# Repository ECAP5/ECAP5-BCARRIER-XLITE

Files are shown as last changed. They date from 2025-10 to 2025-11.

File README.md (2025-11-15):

<br />
<div align="center">
    

  <h3 align="center">ECAP5-BCARRIER-XLITE</h3>

  <p align="center">
    Extra-light carrier board for the ECAP5-BSOM bringup
    <br />
    <a href="https://ecap5.github.io/ECAP5-BCARRIER-XLITE/"><strong>Explore the docs »</strong></a>
    <br />
  </p>
</div>

## Feature status

Status of the board feature's bringup :

<table>
  <thead>
    <tr>
      <th>Feature</th>
      <th>rev-1.0</th>
    </tr>
  </thead>
  <tbody>
    <tr>
      <td>Power input protections</td>
      <td>⏲️</td>
    </tr>
    <tr>
      <td>SOM power</td>
      <td>✅</td>
    </tr>
    <tr>
      <td>SOM JTAG</td>
      <td>⚠️</td>
    </tr>
    <tr>
      <td>SOM reset</td>
      <td>✅</td>
    </tr>
    <tr>
      <td>UART-to-USB</td>
      <td>⛔ (✅ with errata)</td>
    </tr>
    <tr>
      <td>SOM-to-SOM 8x differential-pairs bus</td>
      <td>⏲️</td>
    </tr>
    <tr>
      <td>SOM-to-SOM 16x single-ended bus</td>
      <td>⏲️</td>
    </tr>
    <tr>
      <td>SOM single-ended testpoint</td>
      <td>⏲️</td>
    </tr>
    <tr>
      <td>SOM differential-pair testpoint</td>
      <td>⏲️</td>
    </tr>
    <tr>
      <td>User LEDs</td>
      <td>⚠️</td>
    </tr>
    <tr>
      <td>User Buttons</td>
      <td>⏲️</td>
    </tr>
  </tbody>
</table>

See the [errata](https://ecap5.github.io/ECAP5-BCARRIER-XLITE/errata/1.0.html) for a full description of known issues.

## Licenses

- Software and configuration files are distributed under the GPL-3.0 license.
- Hardware is distributed under the CERN-OHL-S license.

See licence files for more information.

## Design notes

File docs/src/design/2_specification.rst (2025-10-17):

Specification
=============

.. requirement:: U_POWER_01
   :rationale: The board will be powered by a lab bench power supply.

   The board shall include a 2x1 terminal block connector for power input with a voltage range of 9V to 15V.

.. requirement:: U_POWER_02

   The board shall include reverse polarity and ESD protection after the power input connector.

.. requirement:: U_POWER_03

   The board shall include a 9-15V to 3.3V voltage regulator.

.. requirement:: U_POWER_04

   An LED shall be connected to the 3.3V regulator output.

.. requirement:: U_SOM_01

   The board shall include two DDR4-SODIMM connectors.

.. requirement:: U_SOM_02

   Any routing of the DDR4-SODIMM connector pins shall comply with the following pinout.



.. list-table:: SO-DIMM IO Connector Signal Description
   :header-rows: 1
   :width: 100%

   * - Name
     - Type
     - Description

   * - JTAG_TCK
     - I
     - JTAG clock input
   * - JTAG_TDI
     - I
     - JTAG data input
   * - JTAG_TDO
     - O
     - JTAG data output
   * - JTAG_TMS
     - I
     - JTAG test mode select input
   * - SE[0-67]
     - I/O
     - Single-Ended general purpose 3v3 input/output
   * - RTD[0-64][P/N]
     - I
     - General purpose input/output LVDS2V5
   * - RESET_I
     - I
     - Reset input
   * - VIN9_15
     - 
     - Main power input 9~20V
   * - unused
     - 
     - 
   * - GND
     - 
     - 

.. note:: Unused pins are left unconnected but reserved on the connector for future use.

.. requirement:: U_SOM_03

   The VIN9_15 pins of the DDR4-SODIMM connectors shall be connected to the protected 9-15V board power.

.. requirement:: U_SOM_04

   The JTAG pins of the DDR4-SODIMM connectors shall be routed to separate pin headers for each SOM.

.. requirement:: U_SOM_05

  The RESET_IN pins of the DDR4-SODIMM connectors shall be routed to separate tactile switches for each SOM.

.. requirement:: U_BUS_01

  8 differential pairs shall be routed between the two SOMs.

.. requirement:: U_BUS_02

  16 single-ended signals shall be routed between the two SOMs.

.. requirement:: U_UART_01

  The board shall include a USB-to-UART converter.

.. requirement:: U_UART_02

  Pin headers shall be used with jumpers to allow the user to select which of the SOM's UART pins are connected to the USB-to-UART converter.

.. requirement:: U_USER_01

   Two tactile switches shall be connected to one of the SOMs, supplying 3.3V when activated.

.. requirement:: U_USER_02

   Two LEDs shall be connected to one of the SOMs in an open drain configuration.

.. requirement:: U_TEST_01

   One single-ended signal of one of the SOMs shall be routed to a coaxial connector.

.. requirement:: U_TEST_02

   One differencial pair of one of the SOMs shall be routed to two coaxial connectors, one for the true signal and one for the complement..

.. requirement:: U_MECHANICAL_01

   The board shall include M2 mounting holes.

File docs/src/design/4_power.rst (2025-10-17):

(F1) Power
==========

Functional description
----------------------

The power sub-circuit is in charge of reverse-polarity protection and ESD protection on the 9-15V input terminal block using a TVS and a Schottky diode.

The power sub-circuit integrates a 9-15V to 3.3V linear voltage regulator to power the UART sub-circuit up to 300mA.

Design constraints
------------------

N/A

Circuit diagram
---------------

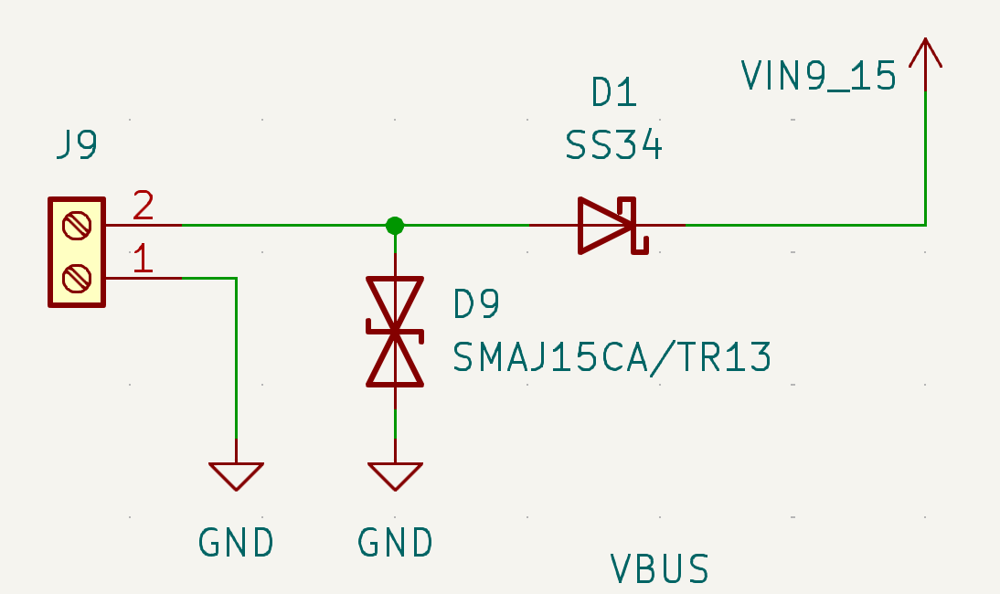
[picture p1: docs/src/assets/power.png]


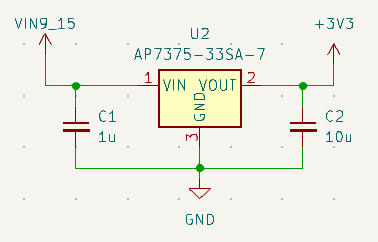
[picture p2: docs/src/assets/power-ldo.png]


Design calculations
-------------------

N/A

Simulation results
------------------

N/A

Power integrity
---------------

N/A

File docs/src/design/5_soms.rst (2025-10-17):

(F2) SOMs
=========

Functional description
----------------------

The SOM sub-circuit integrates two DDR4-SODIMM connectors to integrate two ECAP5-BSOM modules.

.. note:: Refer to the circuit diagram for pinout information.

Design constraints
------------------

N/A

Circuit diagram
---------------

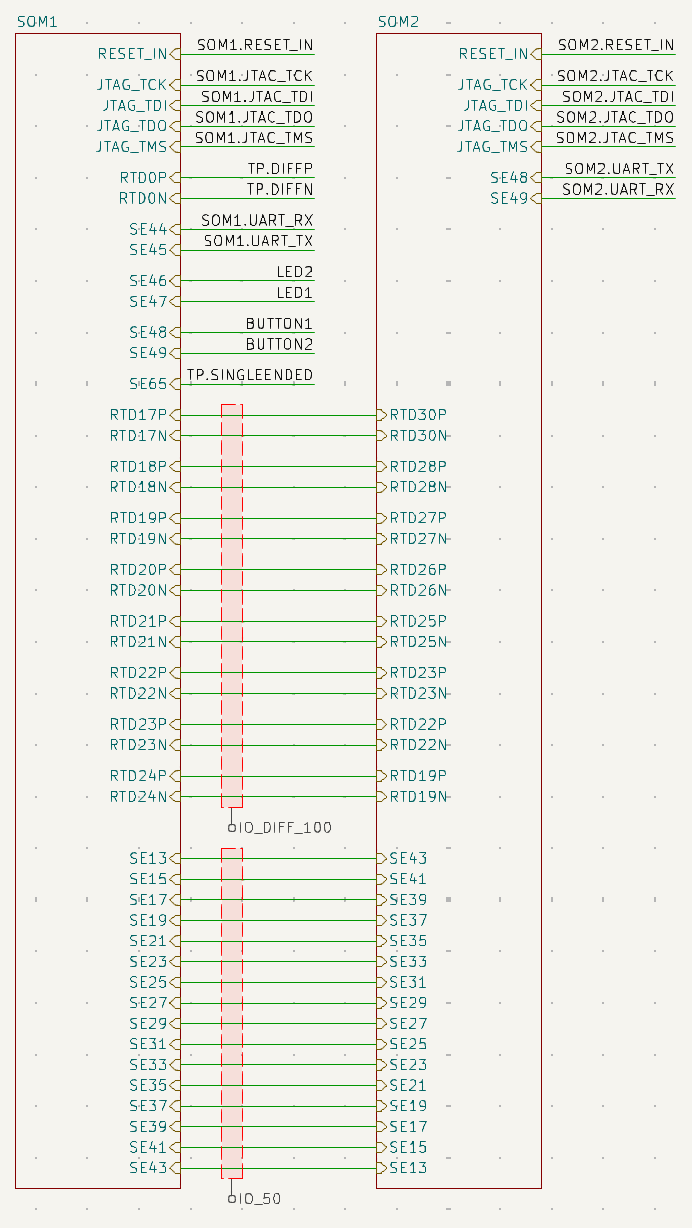
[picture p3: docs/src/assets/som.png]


Design calculations
-------------------

N/A

Simulation results
------------------

N/A

Power integrity
---------------

N/A

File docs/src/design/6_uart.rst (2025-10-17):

(F3) UART
=========

Functional description
----------------------

The UART sub-circuit is in charge of converting UART to USB, routed to the USB-C connector.

The sub-circuit integrates a selector to route either the first or second SOM's UART bus to the converter.

The sub-circuit integrates a way to test the UART-to-USB converter by injecting UART data through the selector connector.



| 

Design constraints
------------------

N/A

Design calculations
-------------------

N/A

Circuit diagram
---------------

N/A

Simulation results
------------------

N/A

Power integrity
---------------

N/A

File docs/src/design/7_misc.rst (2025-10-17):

(F4) Miscellaneous
==================

Functional description
----------------------

The board integrates :

* two active-high user push buttons routed to SOM1
* two active-low reset buttons respectively routed to SOM1 and SOM2
* two green user LEDs routed to SOM1, powered by an NPN BJT transistor
* one 3.3V power green LED
* one SMA testpoint for a single-ended signal routed to SOM1
* two SMA testpoints for a differential signal routed to SOM1
* two 4x1 pin headers for JTAG access to respectively SOM1 and SOM2

Design constraints
------------------

N/A

Circuit diagram
---------------

N/A

Design calculations
-------------------

N/A

Simulation results
------------------

N/A

Power integrity
---------------

N/A

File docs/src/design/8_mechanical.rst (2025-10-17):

Mechanical features
===================

The board includes four M2 unplated holes.

Refer to the following document for full details : `mechanical.pdf <../_static/mechanical.pdf>`_.

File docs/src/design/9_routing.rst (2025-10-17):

Routing
=======

Stackup
-------

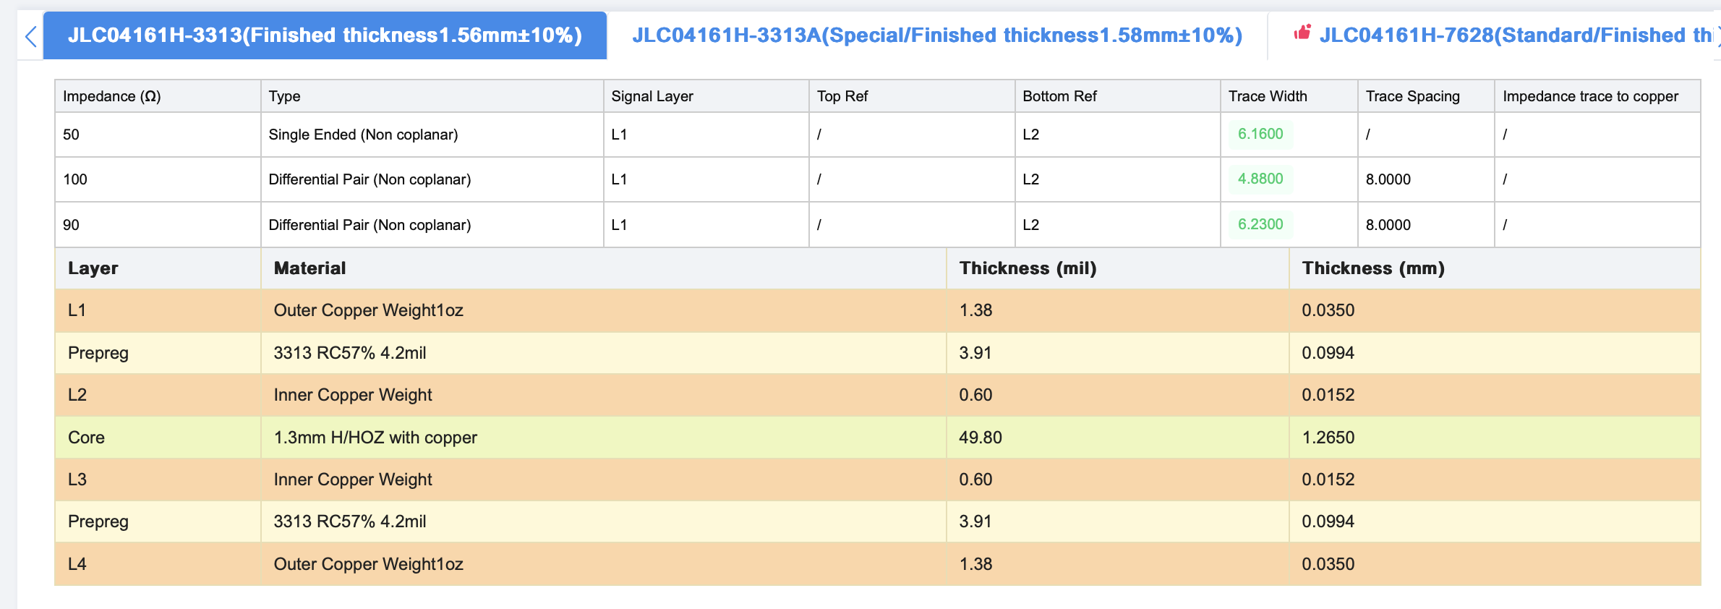
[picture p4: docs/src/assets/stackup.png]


The stackup used is JLCPCB's JLC08121H-3313 1.2mm pcb stackup.

.. flat-table:: Layer allocation
   :header-rows: 1
   :width: 100%

   * - Layer
     - Allocation

   * - Top layer L1
     - High-Speed signals

   * - Inner Layer L2
     - GND

   * - Inner Layer L3
     - Power/GND

   * - Bottom layer L4
     - High-Speed signals

Trace impedance
---------------

.. flat-table:: Net classes
   :header-rows: 1
   :width: 100%

   * - Impedance
     - Layer
     - Trace width
     - Differencial-pair spacing

   * - Single-ended 50ohms
     - L1/L4
     - 6.16mil (0,156464mm)
     - N/A

   * - Differencial 100ohm
     - L1/L4
     - 4.88mil (0,123952mm)
     - 8.0mil (0,2032mm)

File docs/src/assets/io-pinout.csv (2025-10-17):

Signal Name | I/O | Alternate function | Voltage Standards | Differential Pair | DQS Group | Prefered FPGA pin
JTAG_TCK | I |  | LVCMOS33 |  |  | TCK
JTAG_TDI | I |  | LVCMOS33 |  |  | TDI
JTAG_TDO | O |  | LVCMOS33 |  |  | TDO
JTAG_TMS | I |  | LVCMOS33 |  |  | TMS
RS[0-64]P | I | SE[0-130] |  | RS[0-64]N
RS[0-64]N | I | SE[0-130] |  | RS[0-64]P
RTS[0-64]P | I | SE[0-130] |  | RTS[0-64]N
RTS[0-64]N | I | SE[0-130] |  | RTS[0-64]P
RESET_I | I |  | LVCMOS33

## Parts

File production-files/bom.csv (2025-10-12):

Reference | MPN | Qty | Value | DNP | Exclude from BOM | Exclude from Board | Footprint | Part
C1 | CL10A105KB8NNNC | 1 | 1u |  |  |  | Capacitor_SMD:C_0603_1608Metric
C2 | CL10A106KP8NNNC | 1 | 10u |  |  |  | Capacitor_SMD:C_0603_1608Metric
C3,C5 | CL10A475KO8NNNC | 2 | 4.7u |  |  |  | Capacitor_SMD:C_0603_1608Metric
C4,C6,C9 | CC0603KRX7R9BB104 | 3 | 100n |  |  |  | Capacitor_SMD:C_0603_1608Metric
C7,C8 | CL10C470JB8NNNC | 2 | 47p |  |  |  | Capacitor_SMD:C_0603_1608Metric
D1 | SS34 | 1 | SS34 |  |  |  | Diode_SMD:D_SMA
D2,D5,D6,D7,D8 | 150060GS75000 | 5 | 150060GS75000 |  |  |  | LED_SMD:LED_0603_1608Metric
D3,D4 | ESD321DYAR | 2 | ESD321DYAR |  |  |  | Diode_SMD:D_SOD-523
D9 | SMAJ15CA/TR13 | 1 | SMAJ15CA/TR13 |  |  |  | Diode_SMD:D_SMA
FB1 | GZ2012D601TF | 1 | 600R/0.5A |  |  |  | Inductor_SMD:L_0603_1608Metric | MMZ1608Y601BTA00
H1,H2,H3,H4 |  | 4 | MountingHole |  | Excluded from BOM |  | MountingHole:MountingHole_2.2mm_M2
J1,J2 | 2309407-1 | 2 | DDR4_SODIMM_Board |  |  |  | ECAP5-BCARRIER-XLITE:SODIMM-260_DDR4_H4.0-5.2_OrientationStd_Socket | 2309407-2
J3,J4 |  | 2 | Conn_01x04 |  |  |  | Connector_PinHeader_2.54mm:PinHeader_1x04_P2.54mm_Vertical
J5 | USB4105-GF-A-060 | 1 | USB_C_Receptacle_USB2.0_14P |  |  |  | Connector_USB:USB_C_Receptacle_GCT_USB4105-xx-A_16P_TopMnt_Horizontal | USB4105-GF-A
J6,J7,J8 | 132134-10 | 3 | Conn_Coaxial |  |  |  | Connector_Coaxial:SMA_Amphenol_132134-10_Vertical
J9 | WJ127-5.0-2P | 1 | WJ127-5.0-2P |  |  |  | TerminalBlock_Phoenix:TerminalBlock_Phoenix_PT-1,5-2-5.0-H_1x02_P5.00mm_Horizontal
JP1,JP2 |  | 2 | Jumper_3_Open |  |  |  | Connector_PinHeader_2.54mm:PinHeader_1x03_P2.54mm_Vertical
Q1,Q2 | MMBT4401 | 2 | MMBT4401 |  |  |  | Package_TO_SOT_SMD:SOT-23-3
R1,R2 | 0603WAF5101T5E | 2 | 5.1k |  |  |  | Resistor_SMD:R_0603_1608Metric
R3 | 0603WAF4701T5E | 1 | 4.7k |  |  |  | Resistor_SMD:R_0603_1608Metric
R4,R9,R11,R12,R13 | 0603WAF1002T5E | 5 | 10k |  |  |  | Resistor_SMD:R_0603_1608Metric
R5,R6,R7,R8,R10 | 0603WAF1001T5E | 5 | 1k |  |  |  | Resistor_SMD:R_0603_1608Metric
SW1 |  | 1 | RESET_SOM1 |  |  |  | Button_Switch_SMD:SW_Push_1P1T_NO_CK_PTS125Sx43PSMTR | PTS125SM73SMTR21M LFS
SW2 |  | 1 | RESET_SOM2 |  |  |  | Button_Switch_SMD:SW_Push_1P1T_NO_CK_PTS125Sx43PSMTR | PTS125SM73SMTR21M LFS
SW3,SW4 |  | 2 | USER1 |  |  |  | Button_Switch_SMD:SW_Push_1P1T_NO_CK_PTS125Sx43PSMTR | PTS125SM73SMTR21M LFS
U1 | FT232RN | 1 | FT232RN |  |  |  | Package_DFN_QFN:QFN-32-1EP_5x5mm_P0.5mm_EP3.3x3.3mm
U2 | AP7375-33SA-7 | 1 | AP7375-33SA-7 |  |  |  | Package_TO_SOT_SMD:SOT-23-3

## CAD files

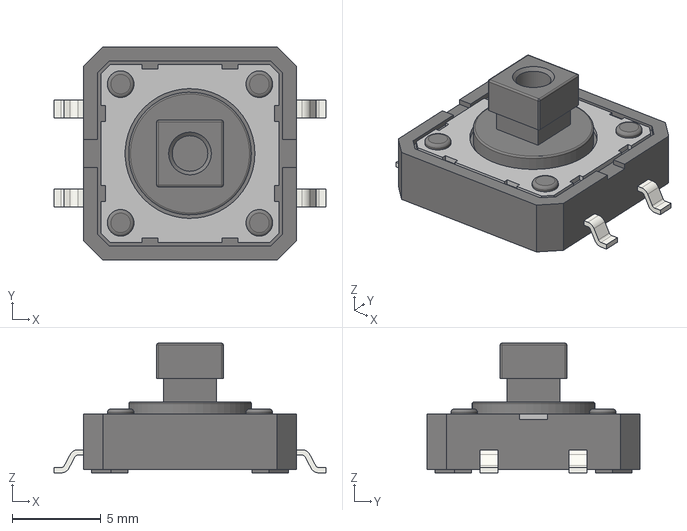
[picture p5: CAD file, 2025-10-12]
src/footprints/models/SW_Push_1P1T_NO_CK_PTS125Sx73SMTR.step
15.3 x 12.0 x 7.30 mm

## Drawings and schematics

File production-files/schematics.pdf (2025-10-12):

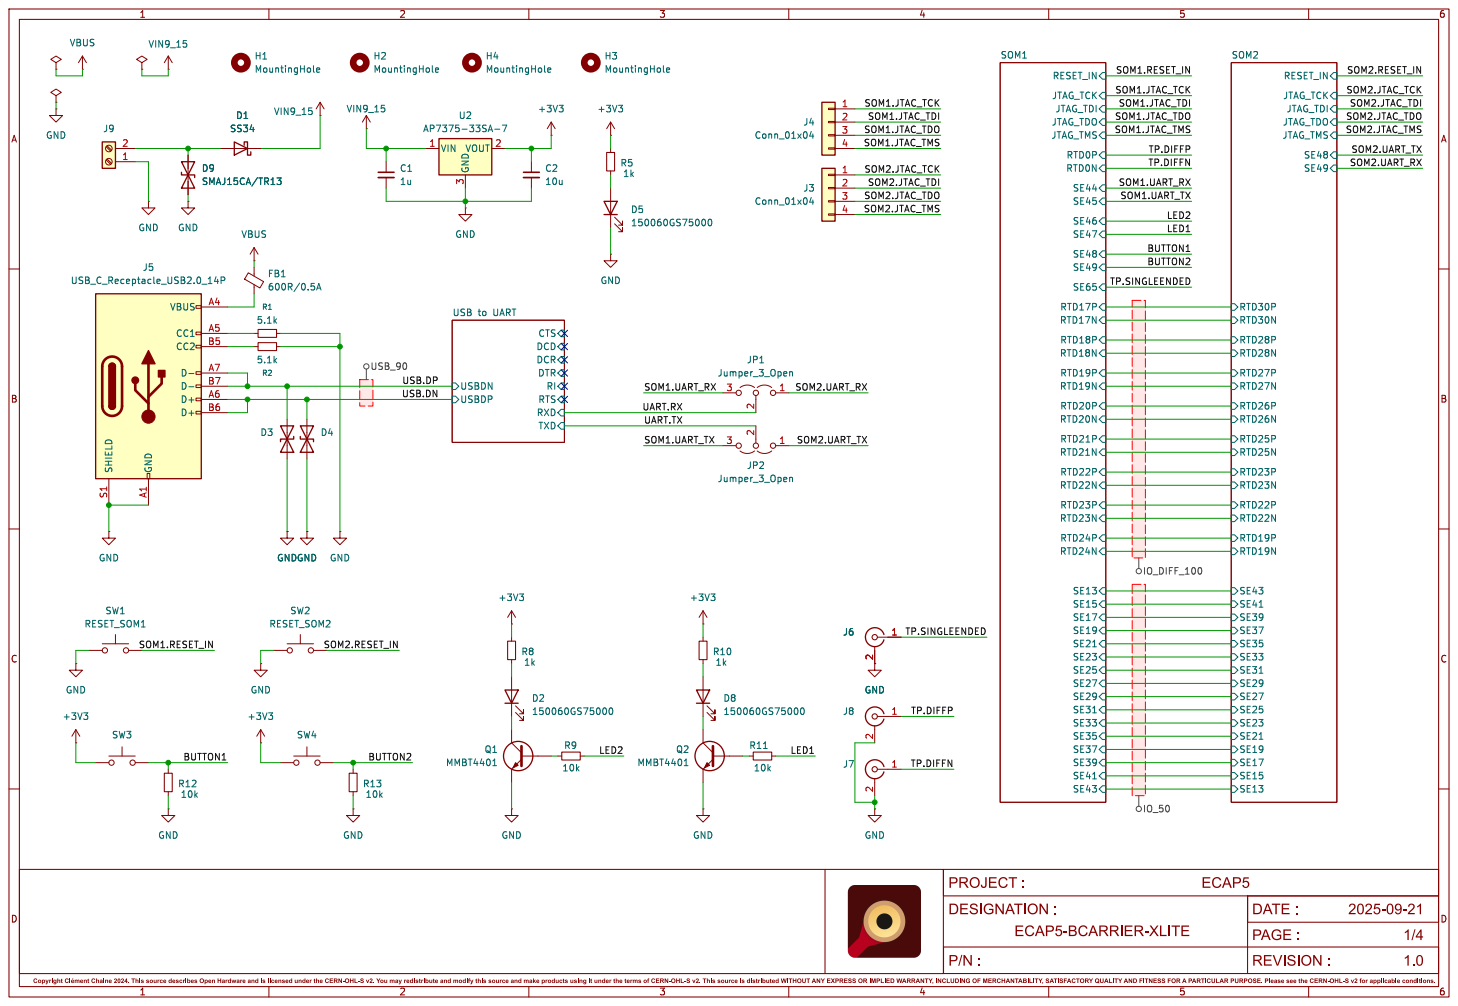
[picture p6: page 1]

TP.DIFFP
TP.DIFFN
LED2 SOM1.UART_RX
LED1 UART.TX UART.RX

USBDP USB to UART

USB.DP USB.DN

REVISION : Copyright þÿClément Chaine 2024. This source describes Open Hardware and is licensed under the CERN-OHL-S v2. You may redistribute and modify this source and make products using it under the terms of CERN-OHL-S v2. This source is distributed WITHOUT ANY EXPRESS OR IMPLIED WARRANTY, INCLUDING OF MERCHANTABILITY,SATISFACTORYQUALITY AND FITNESS FOR A PARTICULAR PURPOSE. Please see the CERN-OHL-S v2 for applicable conditions.

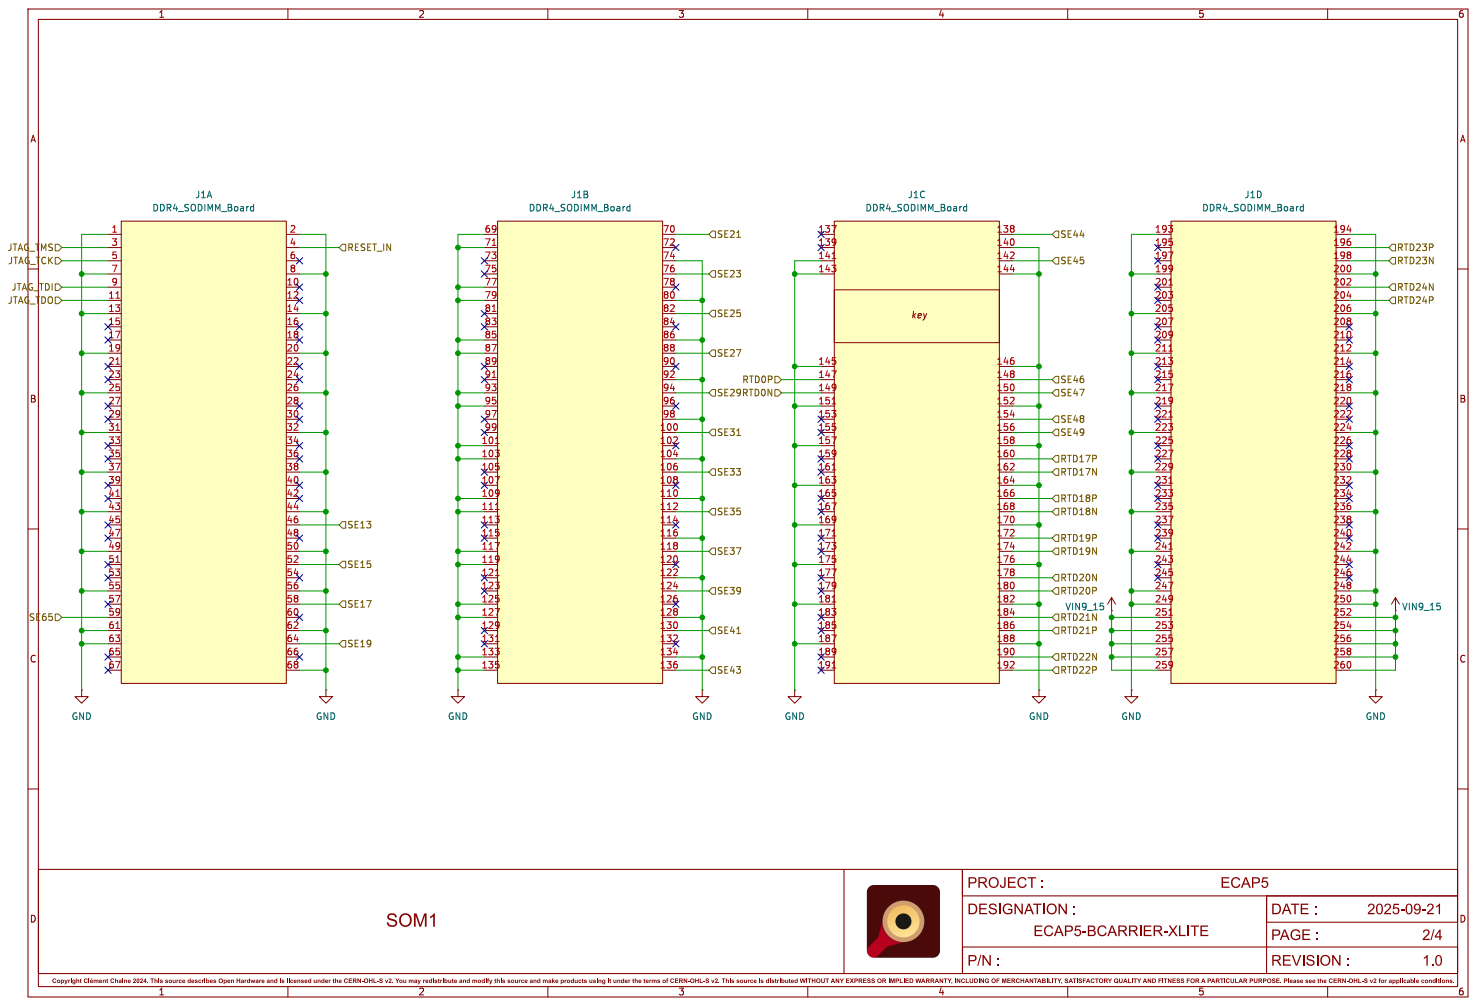
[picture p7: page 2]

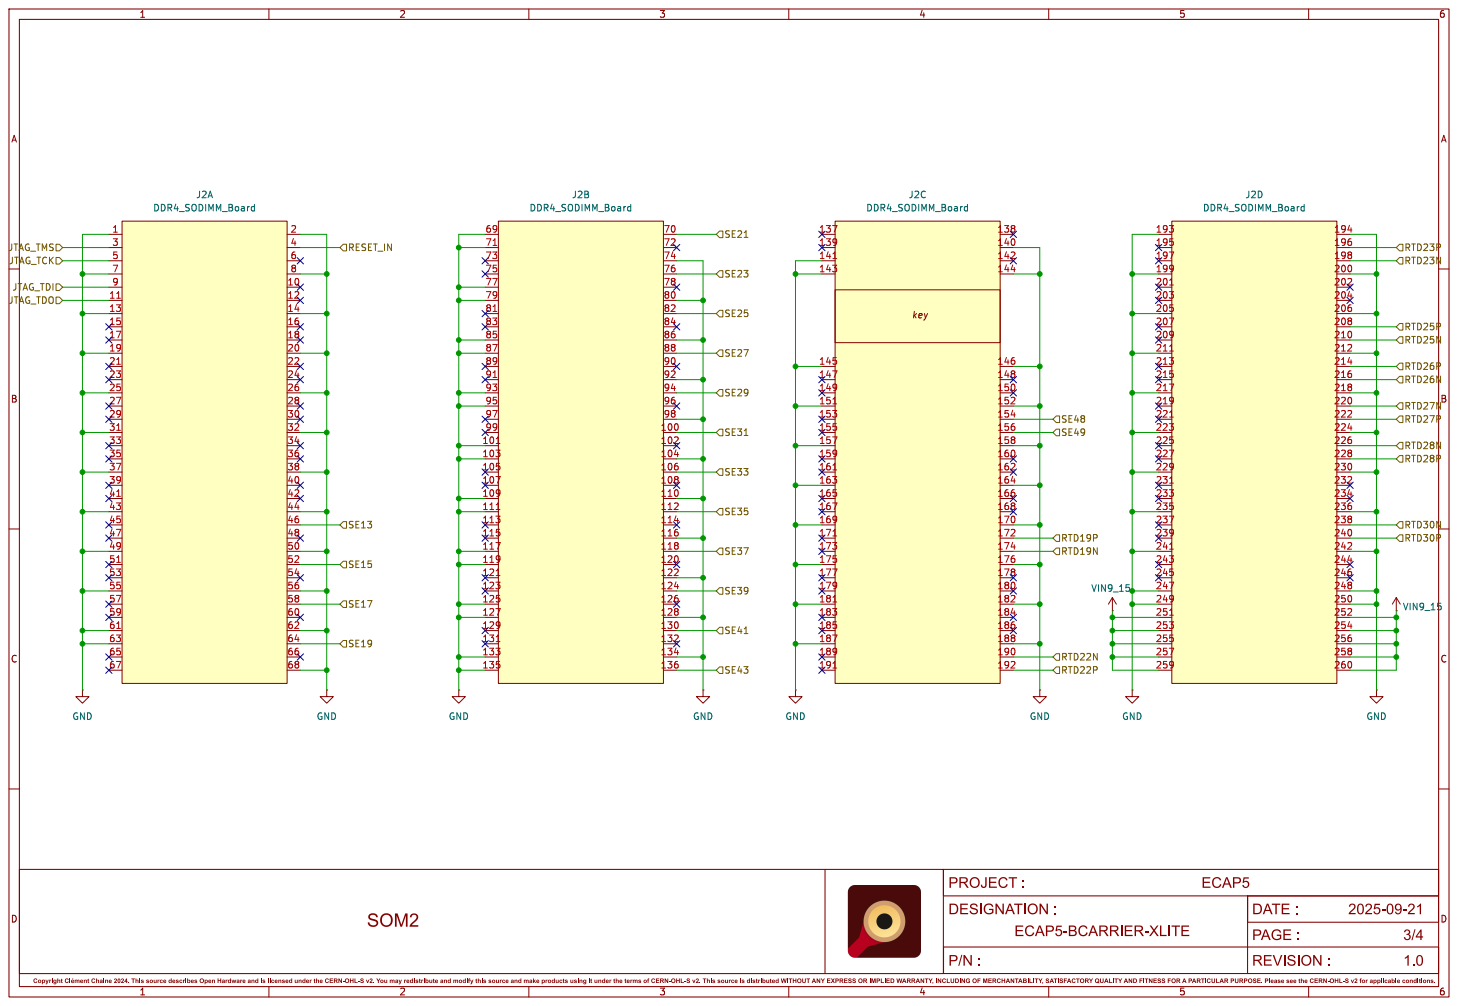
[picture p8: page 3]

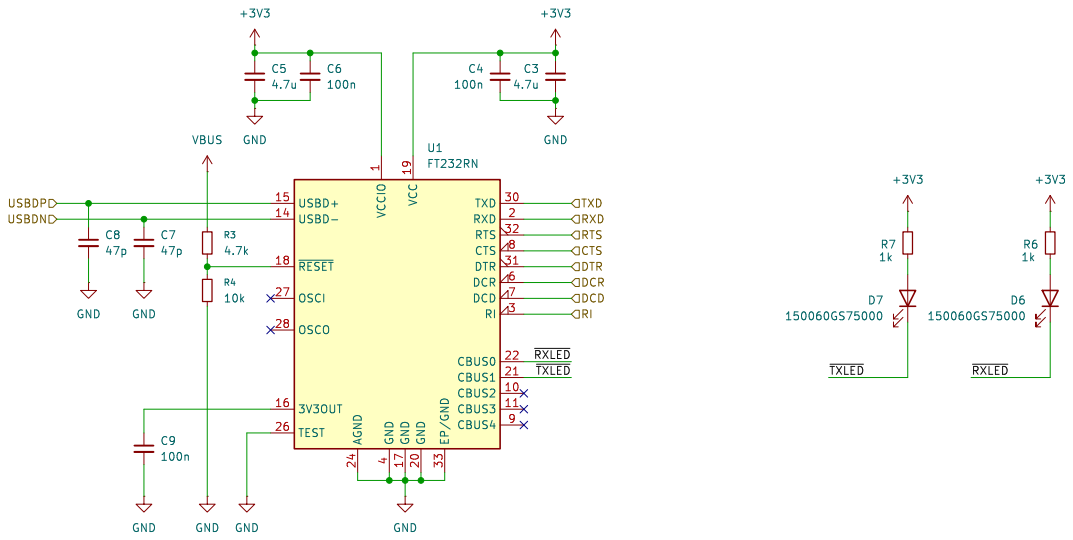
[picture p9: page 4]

4 GND 17 VCC 19 GND 20 EP/GND 33 TXD 30 RXD 2 RTS 32 CTS 8 DTR 31 DCR 6 DCD 7 RI 3 CBUS0 22 CBUS1 21 CBUS2 10 CBUS3 11 CBUS4 9 U1 FT232RN

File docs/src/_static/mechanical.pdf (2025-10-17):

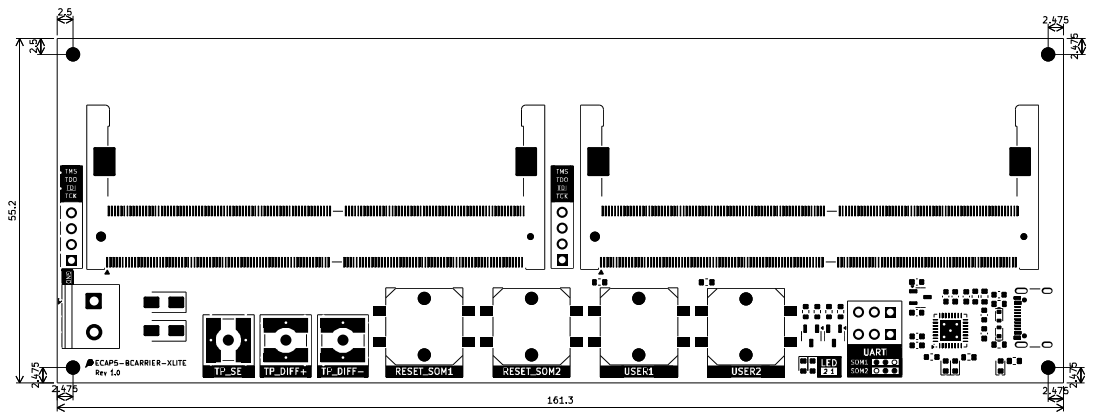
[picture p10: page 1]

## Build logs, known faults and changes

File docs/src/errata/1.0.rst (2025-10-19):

1.0
===

E001 - Inverted USB DP/DM
-------------------------

.. list-table::
   :widths: 10 90

   * - Impacted revision
     - :bdg-muted-line:`1.0`

   * - Criticity
     - :bdg-danger:`critical`

   * - Description
     - The USB signals DP/DM are inverted.

   * - Impact
     - The UART-to-USB sub-circuit does NOT work.

   * - Workaround
     - Reword the board to switch the DP/DM signals.

   * - Linked issue
     - `Issue #11 <https://github.com/ECAP5/ECAP5-BCARRIER-XLITE/issues/11>`_

E002 - Missing pull-down on LEDs
--------------------------------

.. list-table::
   :widths: 10 90

   * - Impacted revision
     - :bdg-muted-line:`1.0`

   * - Criticity
     - :bdg-warning:`moderate`

   * - Description
     - The user LEDs input signal is left floating when unconnected/unused.

   * - Impact
     - The LEDs might randomly turn on.

   * - Workaround
     - Add a pull-down resistor on the LEDs inputs.

   * - Linked issue
     - `Issue #15 <https://github.com/ECAP5/ECAP5-BCARRIER-XLITE/issues/15>`_

E003 - LEDs too bright
----------------------

.. list-table::
   :widths: 10 90

   * - Impacted revision
     - :bdg-muted-line:`1.0`

   * - Criticity
     - :bdg-info:`low`

   * - Description
     - The LEDs are too bright.

   * - Impact
     - Unconfortable to the eye.

   * - Workaround
     - Decrease the current running through the LEDs by changing resistor values.

   * - Linked issue
     - `Issue #16 <https://github.com/ECAP5/ECAP5-BCARRIER-XLITE/issues/16>`_

E004 - USB TVS orientation
--------------------------

.. list-table::
   :widths: 10 90

   * - Impacted revision
     - :bdg-muted-line:`1.0`

   * - Criticity
     - :bdg-warning:`moderate`

   * - Description
     - The part used for the TVS diodes of the USB data signals (ESD321) is uni-directional instead of bidirectional as stated in the schematics, and the orientation of the SOD-523 package is difficult to determine. On the first batch of prototypes, the diodes were soldered in reverse, leading to a non-functional USB connection.

   * - Impact
     - There is a risk of soldering the diodes in reverse, leading to a non-functional UART-to-USB sub-circuit.

   * - Workaround
     - None if soldered properly, remove the diodes otherwise.

   * - Linked issue
     - `Issue #20 <https://github.com/ECAP5/ECAP5-BCARRIER-XLITE/issues/20>`_

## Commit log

2025-08-13 Add initial project
    [ecap5-bcarrier-xlite.kicad_pcb, ecap5-bcarrier-xlite.kicad_sch]
2025-10-12 Add the board design
    * Start adding the schematic
    * Add LED driver
    * Add component footprints
    * Add power planes
    * Start routing the usb interface
    * Route more
    * Route the LVDS pairs
    * Finish routing the single-ended signals
    * Start adding silkscreen
    * Add silkscreen
    * Fix erc issues
    * Save button footprint in local library
    * Fix some drc errors
    * Finish routing the board
    [SW_Push_1P1T_NO_CK_PTS125Sx73SMTR.step, ecap5-bcarrier-xlite.kicad_pcb, ecap5-bcarrier-xlite.kicad_sch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]
2025-10-12 Improve the schematic
    [bom.csv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]
2025-10-17 Finish the documentation
    [io-pinout.csv]
2025-10-17 Add feature status section to README
    Added feature status table to README.md outlining the status of various board features.
2025-10-19 Change UART-to-USB status icon from warning to stop
2025-10-19 Update UART-to-USB status emoji in README
2025-10-19 Update User LEDs status indicator in README
2025-10-19 Add tvs diode errata
2025-10-26 Start adding the uart test script
2025-10-26 Add helloworld uart test script
2025-10-26 Finish the uart test script
2025-10-26 Update UART-to-USB status in README

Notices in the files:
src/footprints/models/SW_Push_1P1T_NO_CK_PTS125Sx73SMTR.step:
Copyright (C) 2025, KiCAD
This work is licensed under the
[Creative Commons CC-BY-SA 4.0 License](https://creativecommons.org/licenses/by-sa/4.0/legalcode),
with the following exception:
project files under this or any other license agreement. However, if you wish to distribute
